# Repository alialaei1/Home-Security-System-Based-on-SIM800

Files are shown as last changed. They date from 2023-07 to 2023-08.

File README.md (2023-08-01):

# Home-Security-System-Based-on-SIM800

Home security system based on SIM800 is a security system that uses a SIM card to send and receive text messages. It is designed to detect any unauthorized entry into a home and alert the homeowner via text message and call to their mobile phone. The system made up of a control panel (main board), sensors, and sirens. 
<br>
<br>
<div align="center"><br></div>
<br>
The sensors can be placed on doors, windows, and other areas around the home to detect any movement or disturbance. When the sensors are triggered, the control panel sends a few calls and text messages to the homeowner's phone, notifying them of the disturbance. This type of home alarm system is often preferred by those who want to be alerted of any security breaches immediately, even if they are not at home. 

<br>
<br>
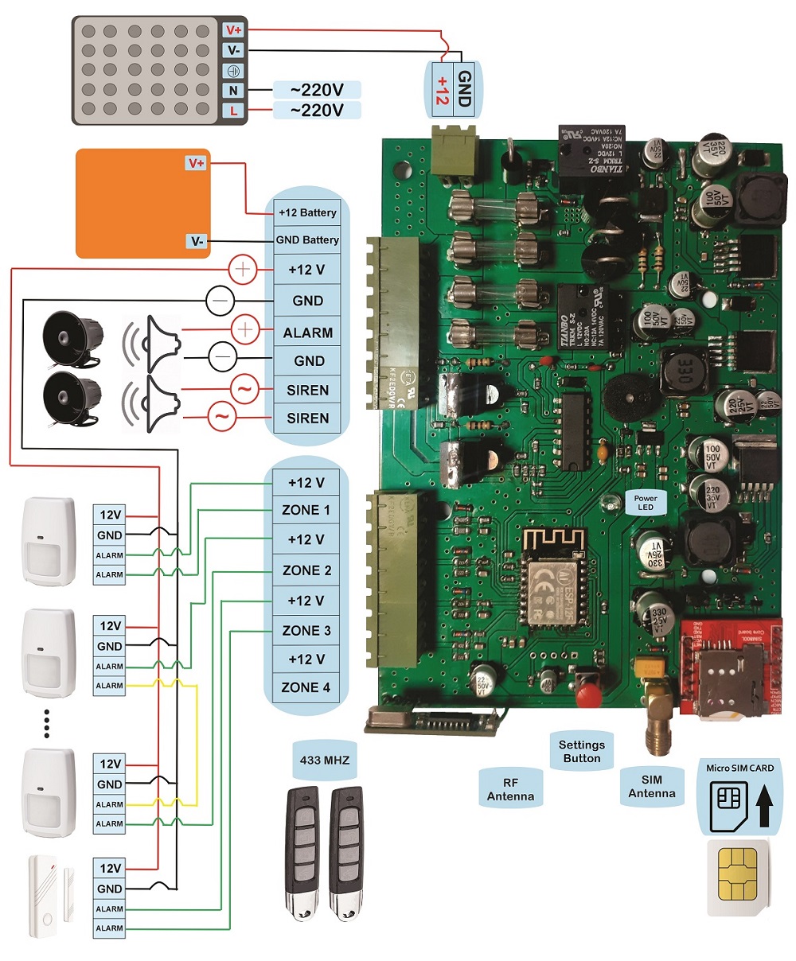
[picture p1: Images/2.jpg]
<div align="center"><br></div>
<br>

Additionally, this type of system can be controlled remotely via text message, allowing the homeowner to turn the system on or off, and to check its status from anywhere at any time.

### This project has been tested more than 4000 hours...

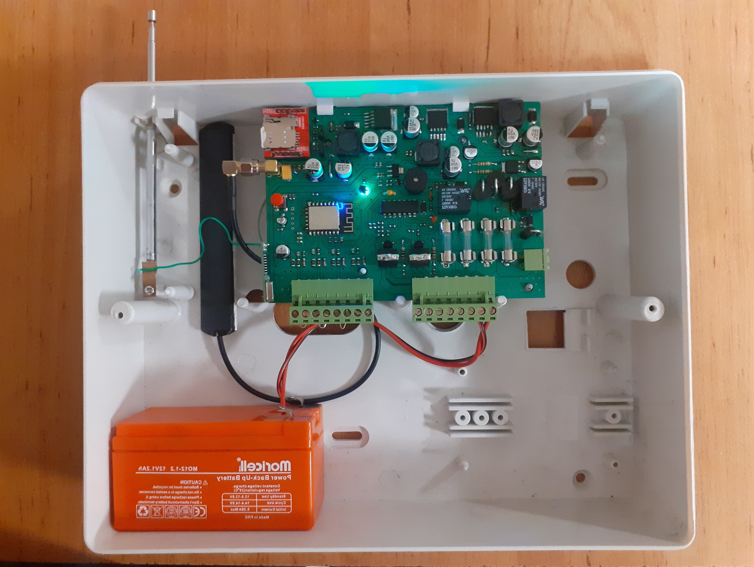
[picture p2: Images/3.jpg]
<div align="center"><br></div>
<br/>

## Features

-  ZONE:
    -  4 wired zones
    -  10 wireless zones for connecting wireless sensors

-  Remote controller:
    -  Supports 10 remote controllers
      
-  Caller memory:
    -  Stores up to 10 mobile phone numbers
      
-  Battery charger:
    -  Equipped with an internal charging and battery protection circuit

 -  Internal siren circuit:
    -  Features a 45-watt internal siren circuit

 -  External antenna socket:
    -  Includes an SMA socket for connecting the SIM800 antenna

 -  IOT:
    -  Allows for internet connection via Wi-Fi

 -  SMS:
    -  Control (on, off, settings) via SMS.
      
<br/>
<br/>
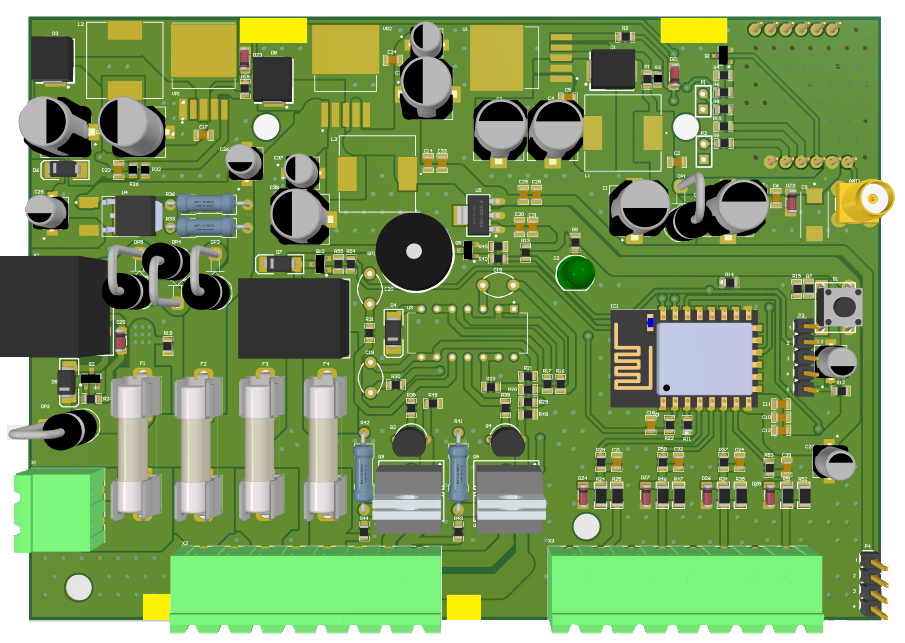
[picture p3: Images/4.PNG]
<div align="center"><br></div>
<br/>

## Setup

### Hardware setup

| Setup  | Description |
| --- | --- |
| Learn wireless sensor | After configuring the sensor address jumpers, press and hold the button on the board for 3 seconds until the board emits 2 consecutive beeps. Now, release the button quickly and move the wireless sensor (connect the sensor power) if you want to learn the sensor. The board will emit 2 consecutive beeps to confirm successful learn. If an error occurs during the learn process, the board will emit only one beep. |
| Remove the wireless sensor | Press and hold the setting button on the board for 3 seconds until the board emits 2 consecutive beeps. Now, quickly release the button and activate the wireless sensor (connect the sensor's power). If the sensor is successfully removed, the board will emit 3 beeps. If there is an error in the deletion process, the board will emit only one beep (similar to the repetition in the sensor Learn process). |
| Learn the remote's Activate button | Press and hold the button on the board for 6 seconds until the board emits 3 consecutive beeps. Now, quickly press the activate button on the remote control. If you successfully learn this button to your device, the board will emit 2 consecutive beeps. If there is an error in the learn process, the board will emit only one beep. |
| Remove the remote's Activate button | Press and hold the button on the board for 6 seconds until the board emits 3 consecutive beeps. Now, quickly release the button and press the activate button on the remote control. If you successfully remove this button from the device, the board will emit 3 consecutive beeps. If there is an error in the deletion process, the board will emit only one beep. |
| Learn the remote's Disable button |  Press and hold the button on the board for 9 seconds until the board emits 4 consecutive beeps. Now, quickly press the disable button on the remote control. If you successfully learn this button to your device, the board will emit 2 consecutive beeps. If there is an error in the learn process, the board will emit only one beep. |
| Remove the remote's Disable button |  Press and hold the button on the board for 9 seconds until the board emits 4 consecutive beeps. Now, quickly release the button and press the disable button on the remote control. If you successfully remove this button from the device, the board will emit 3 consecutive beeps. If there is an error in the deletion process, the board will emit only one beep.|
| Cancel the Learn or Remove process | If you encounter any issues during the process of learn or remove the sensor or remote, or if you wish to cancel the process, simply press the settings button on the board. The device will notify you by emitting a single beep and cancel the process. |
| Erase all remotes and sensors | If you wish to erase all the data and settings on the device, including mobile phone numbers, sensors, activate and disable buttons of remotes, and more, simply hold the button on the device for 20 seconds until the board emits 5 consecutive beeps. Once you release the button, the device's memory will be completely erased. |

### SMS setup

| Setup | Instruction |
| --- | --- |
| Save mobile number |<UniqueCode; mobile number> for example :  ```RIJ111111111111111;09191111111``` |
| Getting the status mobile number | < UniqueCode > for example :  ```RIJ111111111111111``` |
| Delete mobile number | <Special code; mobile number saved> for example :  ```RIJ111111111111111;09191111111``` |
| Activate the device |  ```RIJ ON``` |
| Disable the device |  ```RIJ OFF``` |
| Activate the alarm | ```RIJ SIREN ON``` |
| Disable the alarm | ```RIJ SIREN OFF``` |
| Activate  the notification beep | ```RIJ BEEP ON``` |
| Disable the notification beep | ```RIJ BEEP OFF``` |
| Enable zones | <RIJ ZONE "Number" ON> for example :  ```RIJ ZONE 1 ON``` |
| Disable zones  | <RIJ ZONE "Number" OFF> for example :  ```RIJ ZONE 1 OFF``` |
| Set the Alarm time | <RIJ SIREN "Minutes"> for example :  ```RIJ SIREN 15``` |
| Send USSD code | <RIJ UCODE:"Code"> for example :  ```RIJ UCODE:*11111*11111#``` |
| Set the device time | <RIJ SET TIME: "Time"+"Time Zone"> for example :  ```RIJ SET TIME:22/05/09,23:59:59+18``` |
| Getting the Status of the device | ```RIJ STATUS``` |
| Getting the Status of zones | ```RIJ STATUS ZONE``` |
| Reset the device | ```RIJ RESET``` |

### For detailed information and scripts ```Src/COM.ino```

## License
[MIT License](LICENSE)

Free Hardware!

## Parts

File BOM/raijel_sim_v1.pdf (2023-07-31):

Comment | Description | Designator | Footprint | LibRef | Quantity
Antenna | Antenna | ANT1 | SMA | ANT SMA | 1
330uf-35v | CAP ALUM 220UF 20% 35V SMD | C1, C3, C8 | CAP_EEEFP1V221AV | EEEFP1V221AV | 3
100nF | TOTAL CAPACITOR SMD PACK | C2, C12, C14, C23, C34 | CAP0805 | CAP SMD PACKAGE | 5
100uf-35v | CAP ALUM 220UF 20% 35V SMD | C4, C38 | CAP_EEEFP1V221AV | EEEFP1V221AV | 2
1uF | TOTAL CAPACITOR SMD PACK | C5, C17, C18, C21, C24, C29, C31, C32, C39 | CAP0805 | CAP SMD PACKAGE | 9
10pF | TOTAL CAPACITOR SMD PACK | C6 | CAP0805 | CAP SMD PACKAGE | 1
33pF | TOTAL CAPACITOR SMD PACK | C7 | CAP0805 | CAP SMD PACKAGE | 1
470uF | TC 47uF 25V 10% Case D | C9 | CAPPM7343X310N | TAJD476K025RNJ | 1
22uF | TOTAL CAPACITOR SMD PACK | C10 | CAP0805 | CAP SMD PACKAGE | 1
10uF | TOTAL CAPACITOR SMD PACK | C11 | CAP0805 | CAP SMD PACKAGE | 1
10uf-25v | CAP ALUM 22UF 20% 50V SMD | C13 | CAP_EEEFN1H220UR | EEEFN1H220UR | 1
100nF | CAP Ceramic Total | C15 | CAP Ceramic 5mm | CAP CERAMIC TOTAL SIZE | 1
100uf-50v | CAP ALUM 100UF 20% 50V SMD | C16 | CAP_EEEFN1H101L | EEEFN1H101L | 1
220pF | CAP Ceramic Total | C19, C20 | CAP Ceramic 5mm | CAP CERAMIC TOTAL SIZE | 2
220uf-35v | CAP ALUM 220UF 20% 35V SMD | C22, C35 | CAP_EEEFP1V221AV | EEEFP1V221AV | 2
22uf-50v | CAP ALUM 22UF 20% 50V SMD | C25, C26, C27, C36, C37 | CAP_EEEFN1H220UR | EEEFN1H220UR | 5
4.7uF | TOTAL CAPACITOR SMD PACK | C28, C30, C33 | CAP0805 | CAP SMD PACKAGE | 3
1n5822 | Schottky Rectifiers | D1, D3, D8 | DO-214AB(SMC) | 1N5822 SMD | 3
LED 5MM | Light Emitting Diode | D2 | LED5MM_GRN | LED 5MM | 1
SM4007 | Diode SMD Pakage | D4, D5, D6, D7 | DIODE SMD | Diode SMD Package | 4
SR560 | General Semiconductor. Revision 3A 1000V Silicon Rectifier | DP1, DP2 | DO-201AD - vertical | 1N5408 3A 1000V | 2
6A10 | General Semiconductor. Revision 3A 1000V Silicon Rectifier | DP3, DP4, DP5 | DO-201AD - vertical | 1N5408 3A 1000V | 3
3.3 | DIODE ZENER GENERAL | DZ1, DZ3, DZ4, DZ6, DZ7, DZ8 | SOD80, LL-34 | ZENER GENERAL DIODE | 6
5.5 | DIODE ZENER GENERAL | DZ2 | SOD80, LL-34 | ZENER GENERAL DIODE | 1
6.5 | DIODE ZENER GENERAL | DZ5 | SOD80, LL-34 | ZENER GENERAL DIODE | 1
F=1.0 A | Fuses 5x20 | F1, F2, F3, F4 | Fuse 5x20 With holder pin | Fuse 5x20 with holdeer pins | 4
ESP8266 ESP-12-F | ESP8266 ESP-12-E | IC1 | ESP8266-12E | ESP8266 ESP-12-E | 1
Relay | Relay_SPDT POWER NEEDLE | K1, K2 | Relay 15.40x12.10x13.10 | RELAY General | 2
100uh or 47uh | 47ÂµH Shielded Inductor 3.25A 78mOhm Max Nonstandard | L1 | IND_CDRH127/LDNP-470MC_SUM | CDRH127/LDNP-470MC | 1
47uh or 33uh | 47ÂµH Shielded Inductor 3.25A 78mOhm Max Nonstandard | L2 | IND_CDRH127/LDNP-470MC_SUM | CDRH127/LDNP-470MC | 1
33uh or 47uh | 47ÂµH Shielded Inductor 3.25A 78mOhm Max Nonstandard | L3 | IND_CDRH127/LDNP-470MC_SUM | CDRH127/LDNP-470MC | 1
FHDR_1X02 | Female Header 1X02 | P1, P2 | FHDR1X02-254P | FHDR_1X02 | 2
MHDR_1X05 | Male Header 1X05 | P3 | MHDR1X05-254P | MHDR_1X05 | 1
RX22 | Male Header 1X04 | P4 | MHDR1X04-254P | MHDR_1X04 | 1
BC847C | NPN General-purpose Transistor | Q1, Q2, Q5, Q10 | SOT23_N | BC847C | 4
BC547 | NPN General-purpose Transistor | Q3, Q4 | TO-92 BENT | BC547 | 2
TIP42C | PNP power transistor | Q6, Q7 | TO-220 AB | TIP42C | 2
TIP41C | NPN power transistor | Q8, Q9 | TO-220 AB | TIP41C | 2
2.2k | TOTAL SMD RESISTOR PACK | R1 | RES0805 | RES SMD PACKAGE | 1
1K | TOTAL SMD RESISTOR PACK | R2, R7, R8, R9, R15, R22, R43, R44, R48, R49 | RES0805 | RES SMD PACKAGE | 10
1K | TOTAL SMD RESISTOR PACK | R3, R32 | RES0805_(2012X06L) | RES SMD PACKAGE | 2
47K | TOTAL SMD RESISTOR PACK | R4, R38, R39, R45, R55 | RES0805 | RES SMD PACKAGE | 5
330 | TOTAL SMD RESISTOR PACK | R5 | RES0805 | RES SMD PACKAGE | 1
10K | TOTAL SMD RESISTOR PACK | R6, R11, R12, R13, R14, R18, R19, R27, R30, R31 | RES0805 | RES SMD PACKAGE | 10
5.6K | TOTAL SMD RESISTOR PACK | R10 | RES0805 | RES SMD PACKAGE | 1
2.2M | TOTAL SMD RESISTOR PACK | R16, R17, R20 | RES0805 | RES SMD PACKAGE | 3
1M | TOTAL SMD RESISTOR PACK | R21, R23 | RES0805 | RES SMD PACKAGE | 2
4.7K | TOTAL SMD RESISTOR PACK | R24, R34, R46, R51 | RES1206 | RES SMD PACKAGE | 4
2.2K | TOTAL SMD RESISTOR PACK | R25, R35, R47, R52 | RES1206 | RES SMD PACKAGE | 4
12K | TOTAL SMD RESISTOR PACK | R26 | RES0805_(2012X06L) | RES SMD PACKAGE | 1
4.7K | TOTAL SMD RESISTOR PACK | R28, R37, R50, R53 | RES0805 | RES SMD PACKAGE | 4
2.7M | TOTAL SMD RESISTOR PACK | R29 | RES0805 | RES SMD PACKAGE | 1
15 | RES Axial 0.5W | R33, R36 | Axial 0_5W 5_0mm | RES Axial 0.5W | 2
6K | TOTAL SMD RESISTOR PACK | R40, R54 | RES0805 | RES SMD PACKAGE | 2
100 | RES Axial 0.5W | R41, R42 | Axial 0_5W 5_0mm | RES Axial 0.5W | 2
Switch PB | Push Button Switch | S1 | Switch - Push to On | Switch PB | 1
BUZZER 12V | PIEZO BUZZER ACTIVE | SP1 | BUZZER 7.62mm DC | PIEZO BUZZER | 1
LM2596S-ADJ/NOPB | SIMPLE SWITCHER&reg; 4.5V to 40V, 3A Low Component Count Step-Down Regulator 5-DDPAK/TO-263 -40 to 125 | U1 | VREG_LM2596S-ADJ/NOPB | LM2596S-ADJ/NOPB | 1
SIM800L | | U2 | SIM800L | SIM800L | 1
CD4011BE | | U3 | DIP794W45P254L196 9H508Q14 | CD4011BE | 1
LM317MDTG | Linear Voltage Regulator IC Positive Adjustable 1 Output 500mA DPAK | U4 | VREG_LM317MDTG | LM317MDTG | 1
AMS1117-3V3 | x.x Volt, 800mA Low-Dropout Linear Regulator, 4-pin SOT-223 | U5 | SOT223 | AMS1117-x.x | 1
XL6009 | The XL6009 regulator is a wide input range, current mode, DC/DC converter which is capable of generating either positive or negative output voltages. | VR1 | DPAK170P1435X465-6N | XL6009 | 1
LM2596S-5.0 | | VR2 | TO170P1524X483-6N | LM2596S-5.0 | 1
CON_Phoenix_MSTBA _02 | | X1 | CON_MSTBA02 | CON_Phoenix_MSTBA _02 | 1
CON_Phoenix_MSTBA _08 | | X2, X3 | CON_MSTBA08 | CON_Phoenix_MSTBA _08 | 2

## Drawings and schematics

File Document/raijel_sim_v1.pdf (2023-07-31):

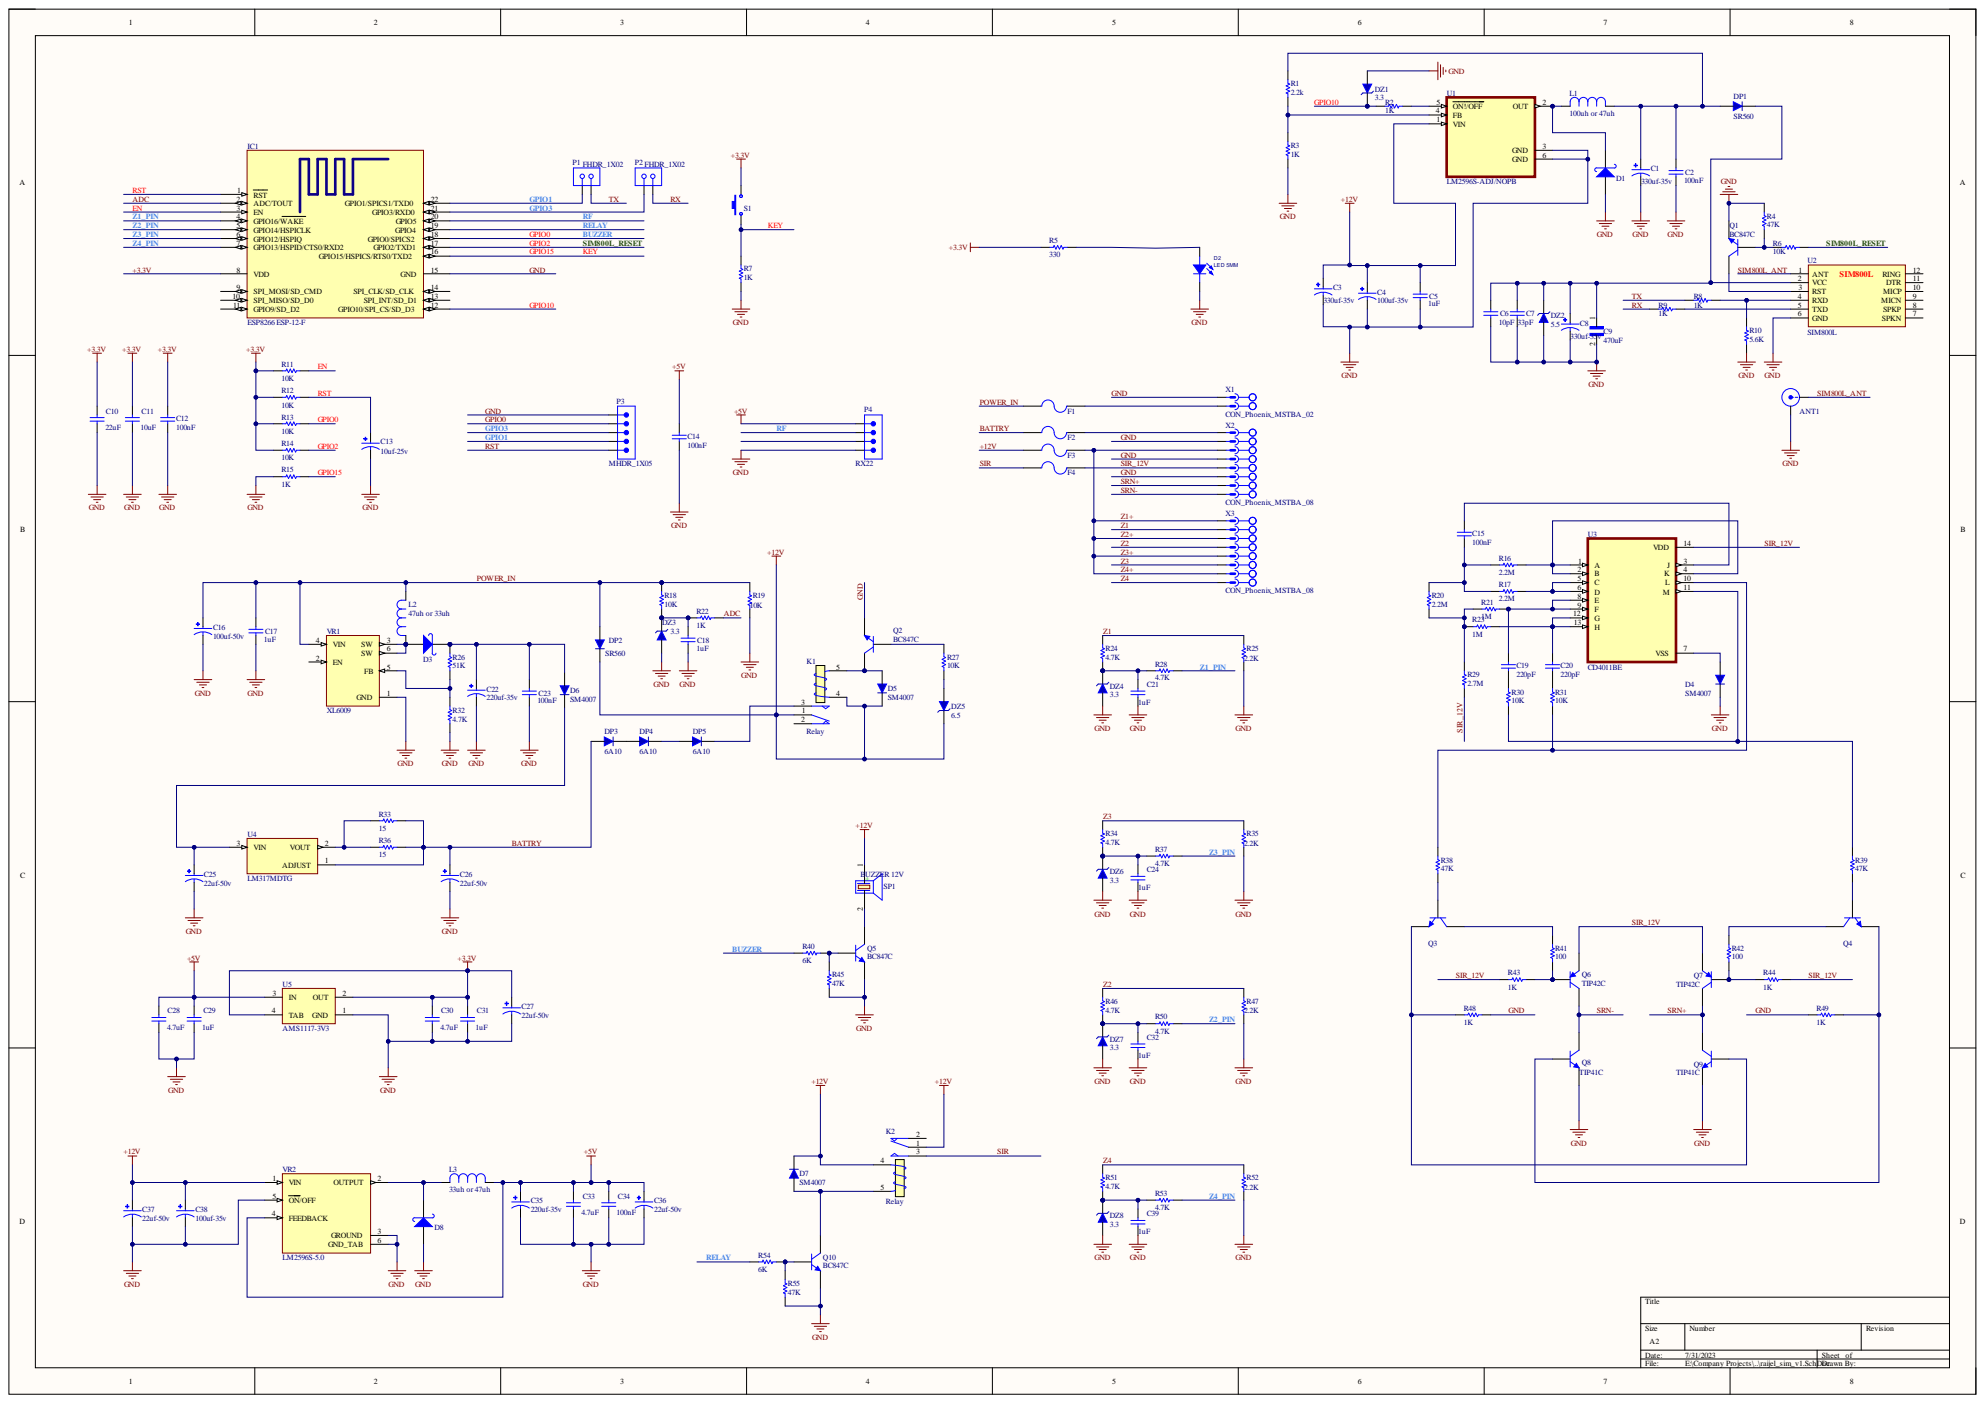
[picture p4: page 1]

1K | FB 4 | 100uh or 47uh | SR560 GND

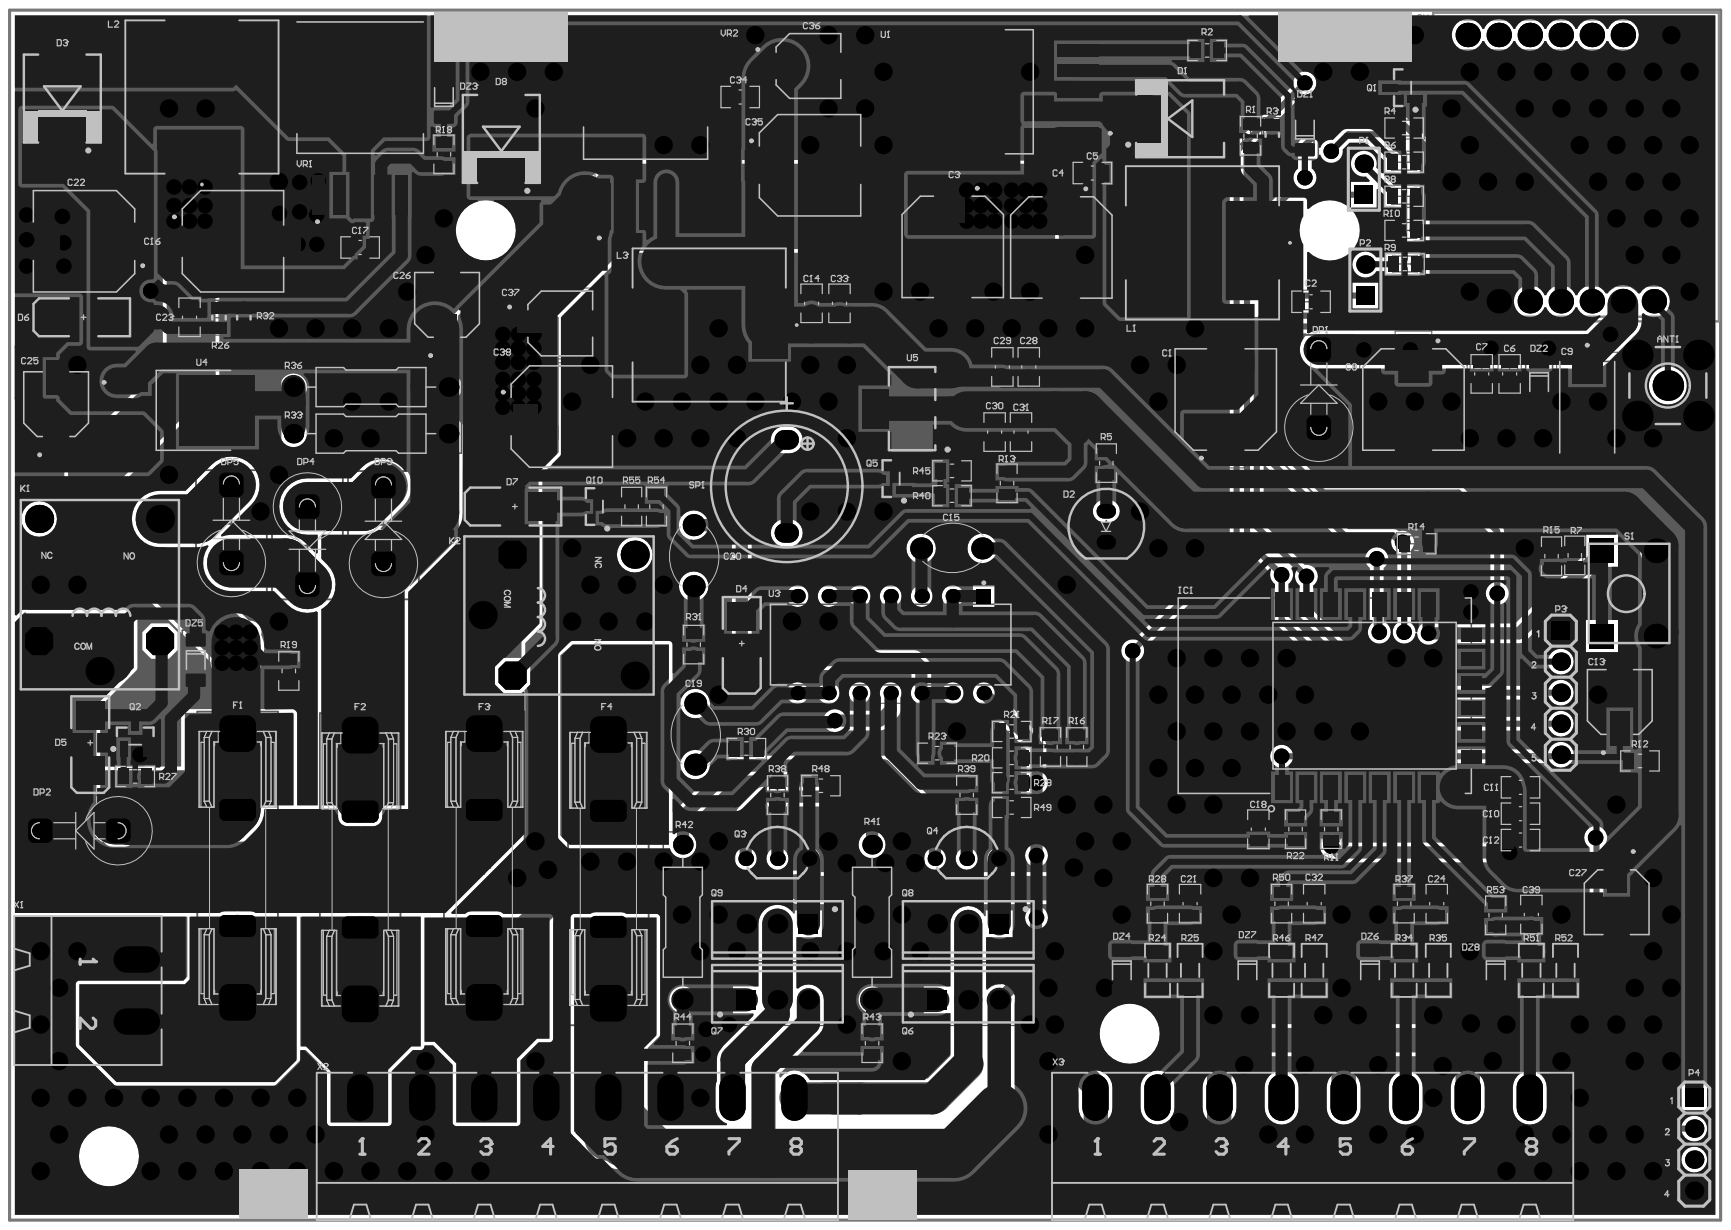
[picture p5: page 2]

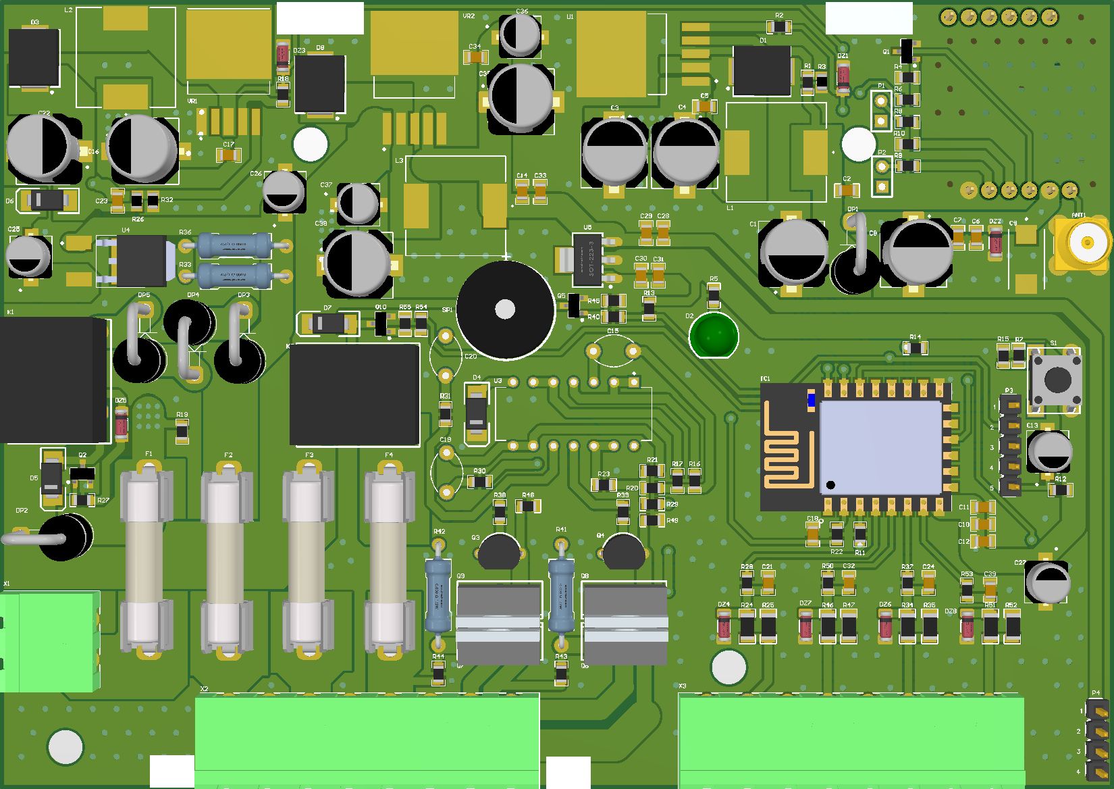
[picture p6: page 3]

Comment | Description | Designator | Footprint | LibRef | Quantity
Antenna | Antenna | ANT1 | SMA | ANT SMA | 1
330uf-35v | CAP ALUM 220UF 20% 35V SMD | C1, C3, C8 | CAP_EEEFP1V221AV | EEEFP1V221AV | 3
100nF | TOTAL CAPACITOR SMD PACK | C2, C12, C14, C23, C34 | CAP0805 | CAP SMD PACKAGE | 5
100uf-35v | CAP ALUM 220UF 20% 35V SMD | C4, C38 | CAP_EEEFP1V221AV | EEEFP1V221AV | 2
1uF | TOTAL CAPACITOR SMD PACK | C5, C17, C18, C21, C24, C29, C31, C32, C39 | CAP0805 | CAP SMD PACKAGE | 9
10pF | TOTAL CAPACITOR SMD PACK | C6 | CAP0805 | CAP SMD PACKAGE | 1
33pF | TOTAL CAPACITOR SMD PACK | C7 | CAP0805 | CAP SMD PACKAGE | 1
470uF | TC 47uF 25V 10% Case D | C9 | CAPPM7343X310N | TAJD476K025RNJ | 1
22uF | TOTAL CAPACITOR SMD PACK | C10 | CAP0805 | CAP SMD PACKAGE | 1
10uF | TOTAL CAPACITOR SMD PACK | C11 | CAP0805 | CAP SMD PACKAGE | 1
10uf-25v | CAP ALUM 22UF 20% 50V SMD | C13 | CAP_EEEFN1H220UR | EEEFN1H220UR | 1
100nF | CAP Ceramic Total | C15 | CAP Ceramic 5mm | CAP CERAMIC TOTAL SIZE | 1
100uf-50v | CAP ALUM 100UF 20% 50V SMD | C16 | CAP_EEEFN1H101L | EEEFN1H101L | 1
220pF | CAP Ceramic Total | C19, C20 | CAP Ceramic 5mm | CAP CERAMIC TOTAL SIZE | 2
220uf-35v | CAP ALUM 220UF 20% 35V SMD | C22, C35 | CAP_EEEFP1V221AV | EEEFP1V221AV | 2
22uf-50v | CAP ALUM 22UF 20% 50V SMD | C25, C26, C27, C36, C37 | CAP_EEEFN1H220UR | EEEFN1H220UR | 5
4.7uF | TOTAL CAPACITOR SMD PACK | C28, C30, C33 | CAP0805 | CAP SMD PACKAGE | 3
1n5822 | Schottky Rectifiers | D1, D3, D8 | DO-214AB(SMC) | 1N5822 SMD | 3
LED 5MM | Light Emitting Diode | D2 | LED5MM_GRN | LED 5MM | 1
SM4007 | Diode SMD Pakage | D4, D5, D6, D7 | DIODE SMD | Diode SMD Package | 4
SR560 | General Semiconductor. Revision 3A 1000V Silicon Rectifier | DP1, DP2 | DO-201AD - vertical | 1N5408 3A 1000V | 2
6A10 | General Semiconductor. Revision 3A 1000V Silicon Rectifier | DP3, DP4, DP5 | DO-201AD - vertical | 1N5408 3A 1000V | 3
3.3 | DIODE ZENER GENERAL | DZ1, DZ3, DZ4, DZ6, DZ7, DZ8 | SOD80, LL-34 | ZENER GENERAL DIODE | 6
5.5 | DIODE ZENER GENERAL | DZ2 | SOD80, LL-34 | ZENER GENERAL DIODE | 1
6.5 | DIODE ZENER GENERAL | DZ5 | SOD80, LL-34 | ZENER GENERAL DIODE | 1
F=1.0 A | Fuses 5x20 | F1, F2, F3, F4 | Fuse 5x20 With holder pin | Fuse 5x20 with holdeer pins | 4
ESP8266 ESP-12-F | ESP8266 ESP-12-E | IC1 | ESP8266-12E | ESP8266 ESP-12-E | 1
Relay | Relay_SPDT POWER NEEDLE | K1, K2 | Relay 15.40x12.10x13.10 | RELAY General | 2
100uh or 47uh | 47ÂµH Shielded Inductor 3.25A 78mOhm Max Nonstandard | L1 | IND_CDRH127/LDNP-470MC_SUM | CDRH127/LDNP-470MC | 1
47uh or 33uh | 47ÂµH Shielded Inductor 3.25A 78mOhm Max Nonstandard | L2 | IND_CDRH127/LDNP-470MC_SUM | CDRH127/LDNP-470MC | 1
33uh or 47uh | 47ÂµH Shielded Inductor 3.25A 78mOhm Max Nonstandard | L3 | IND_CDRH127/LDNP-470MC_SUM | CDRH127/LDNP-470MC | 1
FHDR_1X02 | Female Header 1X02 | P1, P2 | FHDR1X02-254P | FHDR_1X02 | 2
MHDR_1X05 | Male Header 1X05 | P3 | MHDR1X05-254P | MHDR_1X05 | 1
RX22 | Male Header 1X04 | P4 | MHDR1X04-254P | MHDR_1X04 | 1
BC847C | NPN General-purpose Transistor | Q1, Q2, Q5, Q10 | SOT23_N | BC847C | 4
BC547 | NPN General-purpose Transistor | Q3, Q4 | TO-92 BENT | BC547 | 2
TIP42C | PNP power transistor | Q6, Q7 | TO-220 AB | TIP42C | 2
TIP41C | NPN power transistor | Q8, Q9 | TO-220 AB | TIP41C | 2
2.2k | TOTAL SMD RESISTOR PACK | R1 | RES0805 | RES SMD PACKAGE | 1
1K | TOTAL SMD RESISTOR PACK | R2, R7, R8, R9, R15, R22, R43, R44, R48, R49 | RES0805 | RES SMD PACKAGE | 10
1K | TOTAL SMD RESISTOR PACK | R3 | RES0805_(2012X06L) | RES SMD PACKAGE | 1
47K | TOTAL SMD RESISTOR PACK | R4, R38, R39, R45, R55 | RES0805 | RES SMD PACKAGE | 5
330 | TOTAL SMD RESISTOR PACK | R5 | RES0805 | RES SMD PACKAGE | 1
10K | TOTAL SMD RESISTOR PACK | R6, R11, R12, R13, R14, R18, R19, R27, R30, R31 | RES0805 | RES SMD PACKAGE | 10
5.6K | TOTAL SMD RESISTOR PACK | R10 | RES0805 | RES SMD PACKAGE | 1
2.2M | TOTAL SMD RESISTOR PACK | R16, R17, R20 | RES0805 | RES SMD PACKAGE | 3
1M | TOTAL SMD RESISTOR PACK | R21, R23 | RES0805 | RES SMD PACKAGE | 2
4.7K | TOTAL SMD RESISTOR PACK | R24, R34, R46, R51 | RES1206 | RES SMD PACKAGE | 4
2.2K | TOTAL SMD RESISTOR PACK | R25, R35, R47, R52 | RES1206 | RES SMD PACKAGE | 4
51K | TOTAL SMD RESISTOR PACK | R26 | RES0805_(2012X06L) | RES SMD PACKAGE | 1
4.7K | TOTAL SMD RESISTOR PACK | R28, R37, R50, R53 | RES0805 | RES SMD PACKAGE | 4
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

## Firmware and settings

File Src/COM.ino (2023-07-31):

#include "nilinet_librarys.h"
#include "nilinet_pinout.h"
#include "nilinet_var.h"

#include "nilinet_eeprom.h"
#include "nilinet_rf.h"
#include "nilinet_sim.h"



//void SecondsCount_s12() {
//
// if (millis() > StartMilis_s12 + 500) {
//  StartMilis_s12 = millis();
// 
//  if (button.getState() == 1) {
//    if (sim_task.isEnabled() == 1) {
//      sim_task.disable();
//    }
//  }
//  else {
//    if (sim_task.isEnabled() == 0) {
//      sim_task.enable();
//    }
//  }
//}

  //  if (millis() > StartMilis_s12 + 1000) {
  //    StartMilis_s12 = millis();
  //    TIMER_S12++;
  //    if (TIMER_S12 >= 60  && TIMER_S12 < 70 ) {
  //      if (sim_task.isEnabled() == 0) {
  //        TIMER_S1 = 3600;
  //        sim_task.enable();
  //      }
  //    }
  //    if (TIMER_S12 < 60) {
  //      if (sim_task.isEnabled() == 1) {
  //        POWER_SIM800L_ACTION.beep(50000);
  //        sim_task.disable();
  //      }
  //    }
  //  }


//}


void setup() {

  EEPROM.begin(512);

  Serial.begin(9600);
  //mySerial.begin(115200);



  Scheduler.start(&rf_task);
  Scheduler.start(&sim_task);

  Scheduler.begin();
}

void loop() {
  //SecondsCount_s12();
}



//
//
//void setup() {
//
//  WiFi.mode(WIFI_OFF);
//
//  Serial.begin(115200);
//  mySerial.begin(115200);
//
//  mySwitch.enableReceive(RF_Receiver_Pin);
//
//  button.setDebounceTime(100);
//  //ZONE1_isPressed.setDebounceTime(100);
//  //ZONE2_isPressed.setDebounceTime(100);
//  //ZONE3_isPressed.setDebounceTime(100);
//  //ZONE4_isPressed.setDebounceTime(100);
//
//  EEPROM.begin(512);
//
//  EEPROM_GET_ALL_DATA();
//
//
//
//  delay(1000);
//
////  Serial.println("AT\r");
////  delay(200);
////  Serial.println("AT\r");
////  delay(200);
////  Serial.println("AT\r");
////  delay(200);
////  delay(5000);
//
//   mySerial.write("RESET !!!!!");
//  SIM800L_DEFALT() ;
//
//}
//
//
//
//
//void loop() {
//  ////rf
//
//  LOOPER();
//  STATUS_POWER();
//  STATUS_STATIC_ZONE();
//  STATUS_BUTTON();
//  RF_MODULE();
//  SIREN_PROCESS();
//
//
//
//  ////sim
//  SecondsCount();
//  SIM800L_ERORR_CHECK();
//  SIM800L_TIME_CHECK();
//  SMS_DETECTION();
//  SMS_DECODE();
//  SMS_SEND();
//
//
//  //ESP.wdtFeed();
//  //      if (mySerial.available()){
//  //      Serial.write(mySerial.read());}
//  //    if (Serial.available()){
//  //      mySerial.write(Serial.read());}
//
//}

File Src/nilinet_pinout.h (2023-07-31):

//pin out
#define KAY_Pin 15
#define RALAY_Pin 4
#define BUZZER_Pin 0
#define RF_Receiver_Pin 5
#define ZONE1_Pin 16
#define ZONE2_Pin 14
#define ZONE3_Pin 12
#define ZONE4_Pin 13
#define Analog_Pin A0
#define SIM800L_RESET_Pin 2

#define SIM800L_POWER_Pin 10

//timing
#define timeset1 3
#define timeset2 6
#define timeset3 9
#define timeset4 20

RCSwitch mySwitch = RCSwitch();

ezButton button(KAY_Pin);

ezButton ZONE1_isPressed(ZONE1_Pin);
ezButton ZONE2_isPressed(ZONE2_Pin);
ezButton ZONE3_isPressed(ZONE3_Pin);
ezButton ZONE4_isPressed(ZONE4_Pin);

//SoftwareSerial mySerial(12, 14); // RX, TX

ezBuzzer buzzer(BUZZER_Pin);
ezBuzzer RALAY_ACTION(RALAY_Pin);
ezBuzzer RESET_SIM800L_ACTION(SIM800L_RESET_Pin);
ezBuzzer POWER_SIM800L_ACTION(SIM800L_POWER_Pin);

ESP32Time rtc(0);
